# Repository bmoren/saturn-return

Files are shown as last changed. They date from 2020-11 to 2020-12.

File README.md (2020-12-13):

# saturn-return
Send transmissions, listen for communication

## ** REV2 boards are  currently untested **

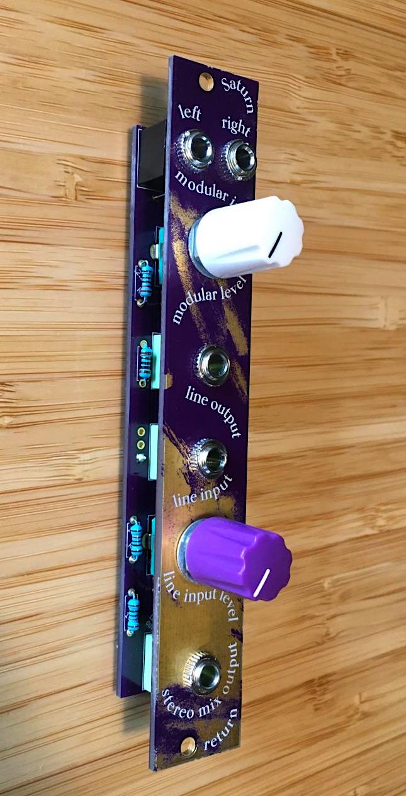
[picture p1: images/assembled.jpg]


Modular level > stereo line out &amp; stereo aux send mixer (a friend of norns)
4hp

Modular Left and Right signals are fed through a voltage divider, tuned, and sent out into space.      
Transmissions are received as stereo line signals.     
Transmissions are tuned and combined with signals (for recording and archiving).    

An module and idea based on [discussion in the norns I/O thread](https://llllllll.co/t/norns-audio-in-out-specs/30256/37?u=bmoren)

[View it on ModularGrid](https://www.modulargrid.net/e/other-unknown-saturn-return)

## I/O

Inputs:
+ L/R modular level signals
+ Line input

Outputs: 
+ Stereo line output
+ Stereo mix line output (mixed inputs)

Knobs:
+ Level control for modular input to mix
+ Level control for line input to mix

Pin headers:
support alternative I/O configurations, non-eurorack builds, and general experimentation!

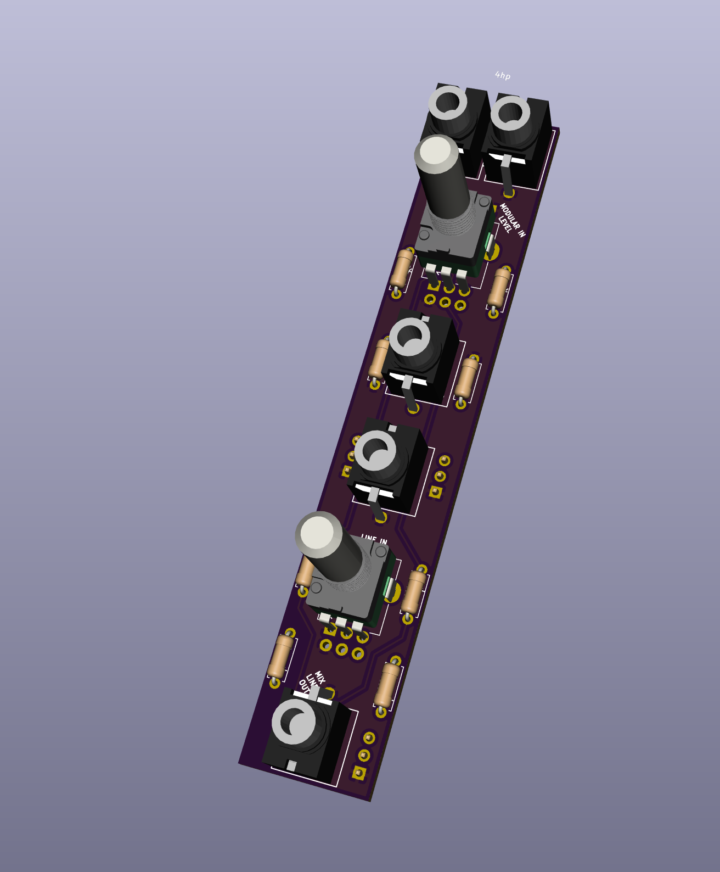
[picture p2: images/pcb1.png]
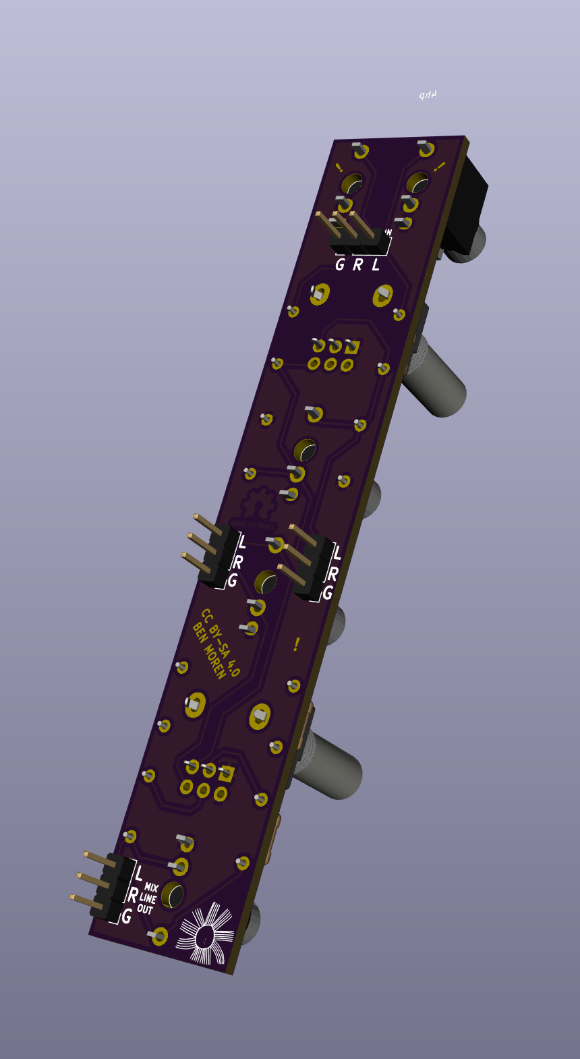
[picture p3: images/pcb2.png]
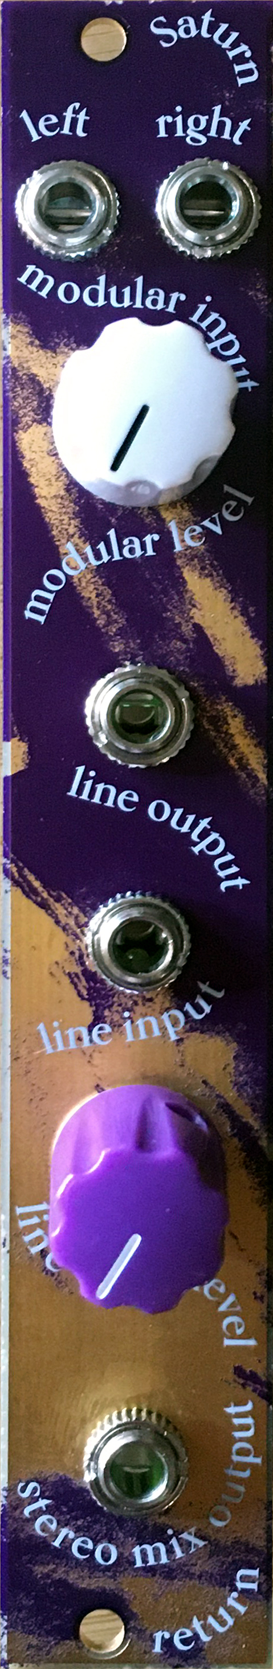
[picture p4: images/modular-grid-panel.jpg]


## Build Instructions
1. (optional advanced preperation – use your multimeter to find matched resistor values R3=R7, R4=R8, R1=R2=R5=R6 )
1. Start with the resistors, place them into the footrpints
1. Solder resistors, clip the legs
1. Place jacks and pots into the footprints. * do not solder them yet!
1. Place the panel on, screw down jacks and pots to the panel (this will align everything)
1. finally solder the jacks and panels
1. attach knobs
1. done!

## BOM
+ 2X [Thonkiconn Jacks](https://www.thonk.co.uk/shop/3-5mm-jacks/)
+ 3X [Thonkiconn Stereo Jacks](https://www.thonk.co.uk/shop/3-5mm-jacks/)
+ 2X [Alpha A10k dual gang potentiometers](https://www.thonk.co.uk/shop/alpha-9mm-pots-dshaft/)
+ 4X 10k Resistor
+ 2X 1k Resistor
+ 2X 2.2k Resistor
+ Optional: 4X 3 position 2.54mm pin header

## license 

CC BY-SA 4.0     
Build and use at your own risk! I am not responsible for any damage to self or otherwise that arises from using this project!

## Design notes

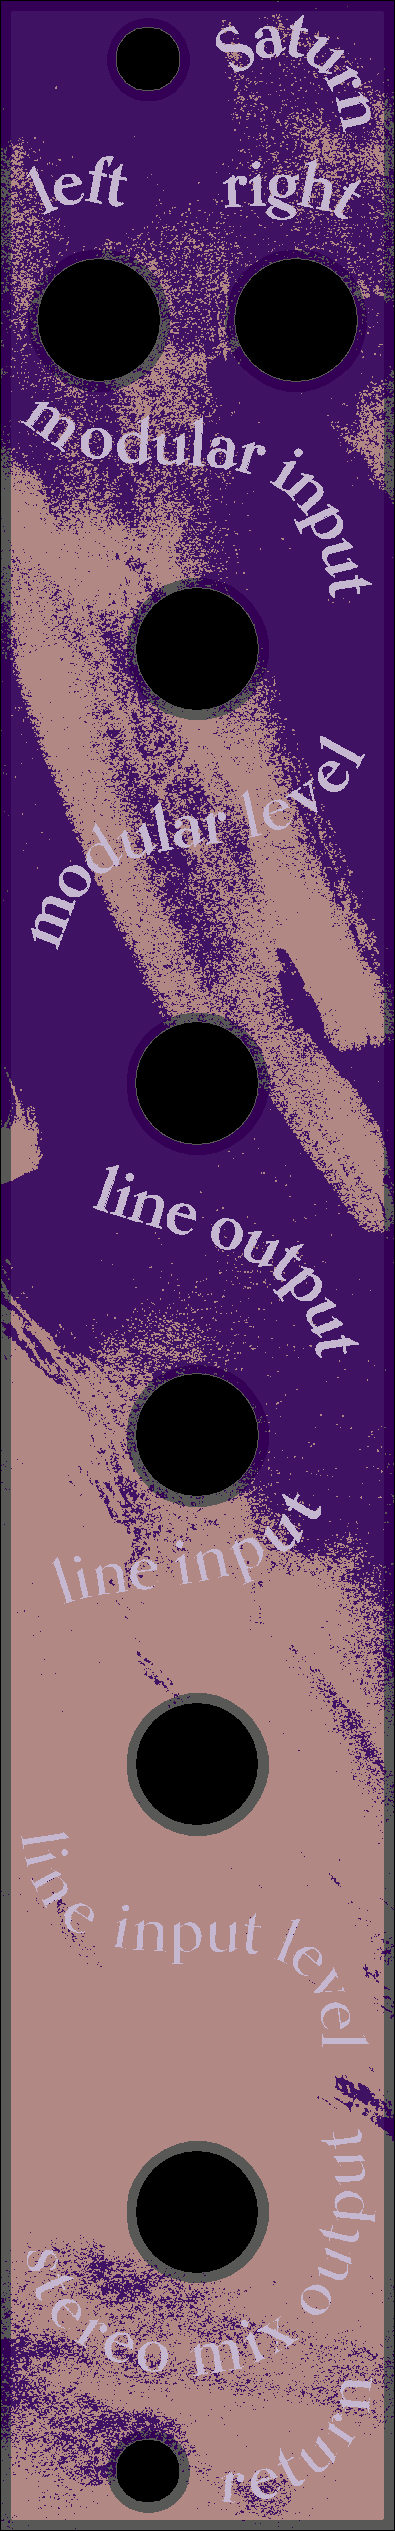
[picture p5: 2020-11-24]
images/panel.png

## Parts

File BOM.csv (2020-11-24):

Source: | /Users/bmoren/Desktop/module development/saturn return/nab.sch
Date: | Tuesday, November 24, 2020 at 02:54:47 PM
Tool: | Eeschema (5.1.6-0-10_14)
Generator: | /Applications/KiCad/kicad.app/Contents/SharedSupport/plugins/bom_csv_grouped_by_value_with_fp.py
Component Count: | 19
Ref | Qnty | Value | Cmp name | Footprint | Description | Vendor
J1, | 1 | MIX LINE OUT | AudioJack3 | modular:Thonkiconn_stereo_small_holes | Audio Jack, 3 Poles (Stereo / TRS)
J2, | 1 | LINE IN | AudioJack3 | modular:Thonkiconn_stereo_small_holes | Audio Jack, 3 Poles (Stereo / TRS)
J3, | 1 | LINE OUT | AudioJack3 | modular:Thonkiconn_stereo_small_holes | Audio Jack, 3 Poles (Stereo / TRS)
J4, | 1 | MOD IN L | thonkiconn | modular:Thonkiconn_small_holes | 2-pin audio jack receptable (mono/TS connector) with switching contact
J5, | 1 | MOD IN R | thonkiconn | modular:Thonkiconn_small_holes | 2-pin audio jack receptable (mono/TS connector) with switching contact
J6, J7, J8, J9, | 4 | Conn_01x03_Male | Conn_01x03_Male | Connector_PinHeader_2.54mm:PinHeader_1x03_P2.54mm_Vertical | Generic connector, single row, 01x03, script generated (kicad-library-utils/schlib/autogen/connector/)
R1, R2, R5, R6, | 4 | 10K | R | Resistor_THT:R_Axial_DIN0207_L6.3mm_D2.5mm_P7.62mm_Horizontal | Resistor
R3, R7, | 2 | 2.2k | R | Resistor_THT:R_Axial_DIN0207_L6.3mm_D2.5mm_P7.62mm_Horizontal | Resistor
R4, R8, | 2 | 1k | R | Resistor_THT:R_Axial_DIN0207_L6.3mm_D2.5mm_P7.62mm_Horizontal | Resistor
RV1, RV2, | 2 | A10k | R_POT_Dual_Separate | Potentiometer_THT:Potentiometer_Alpha_RD902F-40-00D_Dual_Vertical | Dual potentiometer, separate units

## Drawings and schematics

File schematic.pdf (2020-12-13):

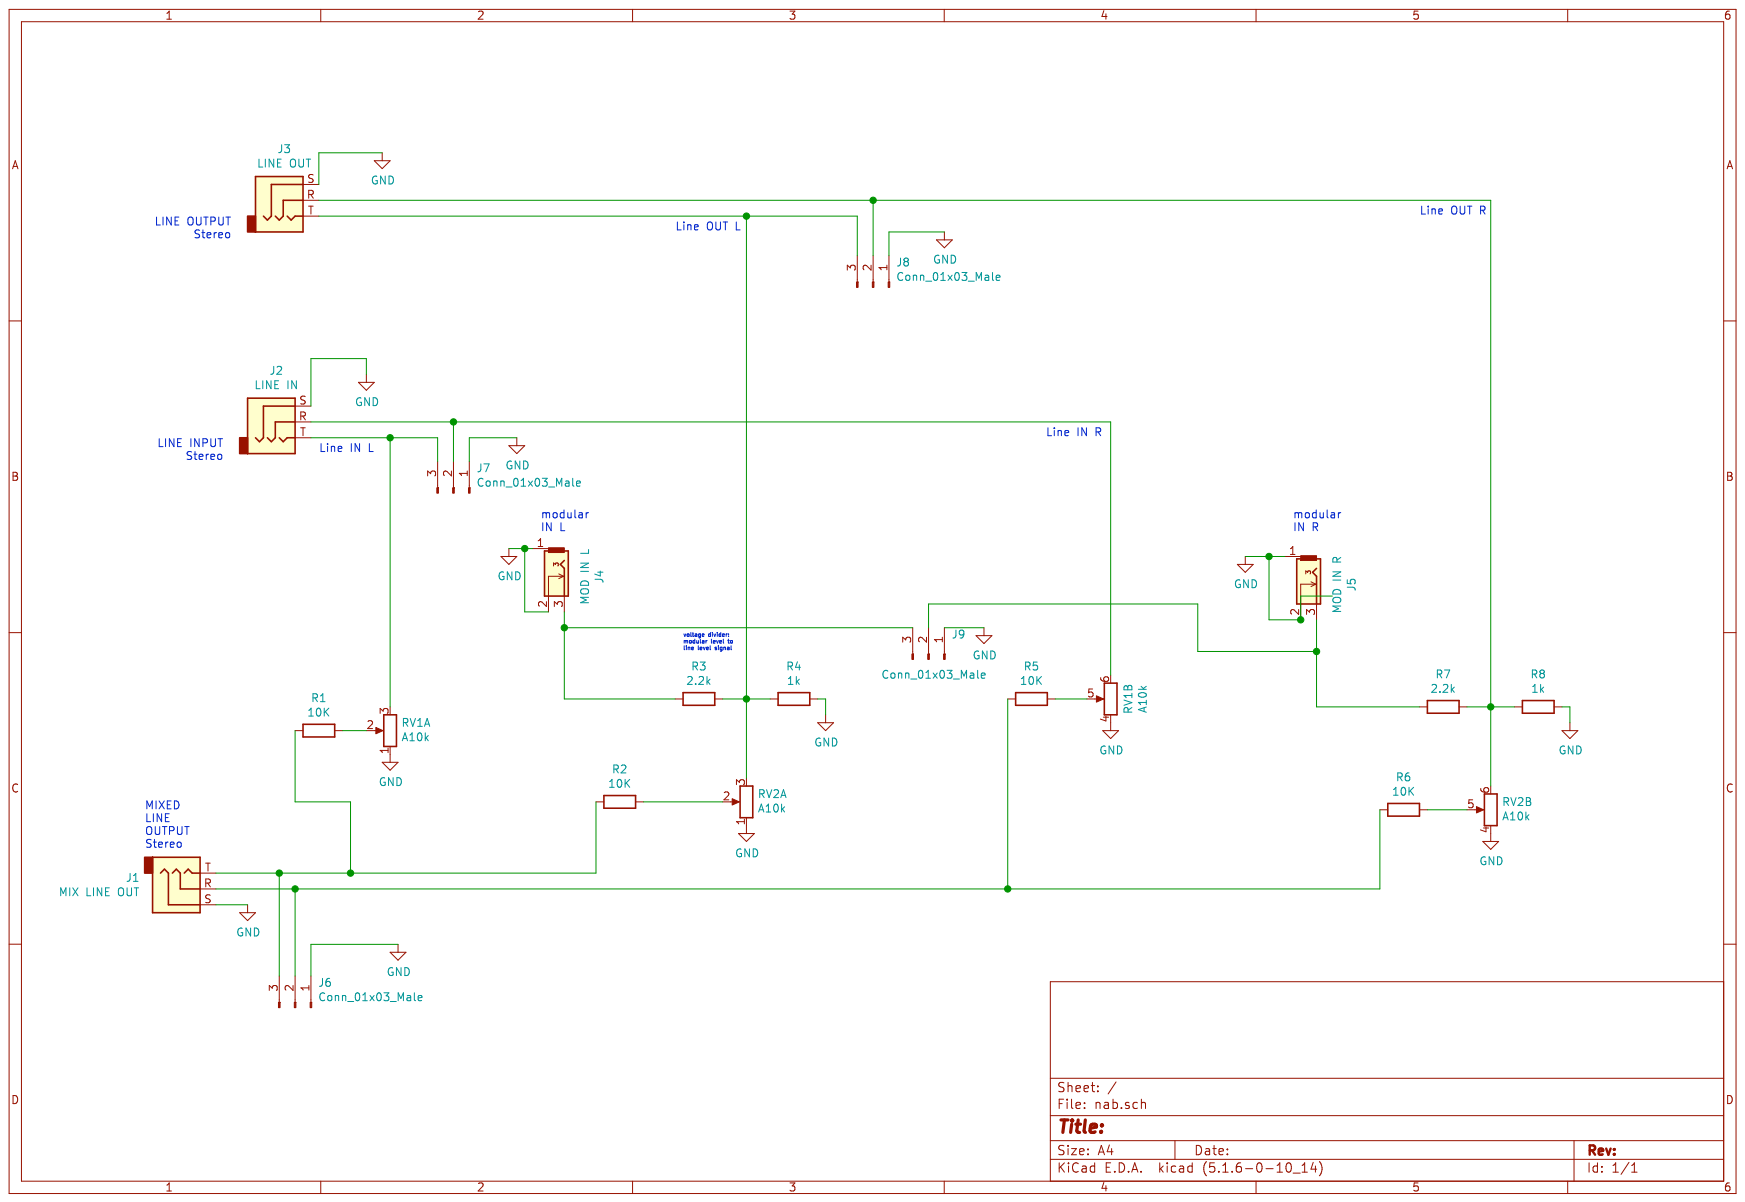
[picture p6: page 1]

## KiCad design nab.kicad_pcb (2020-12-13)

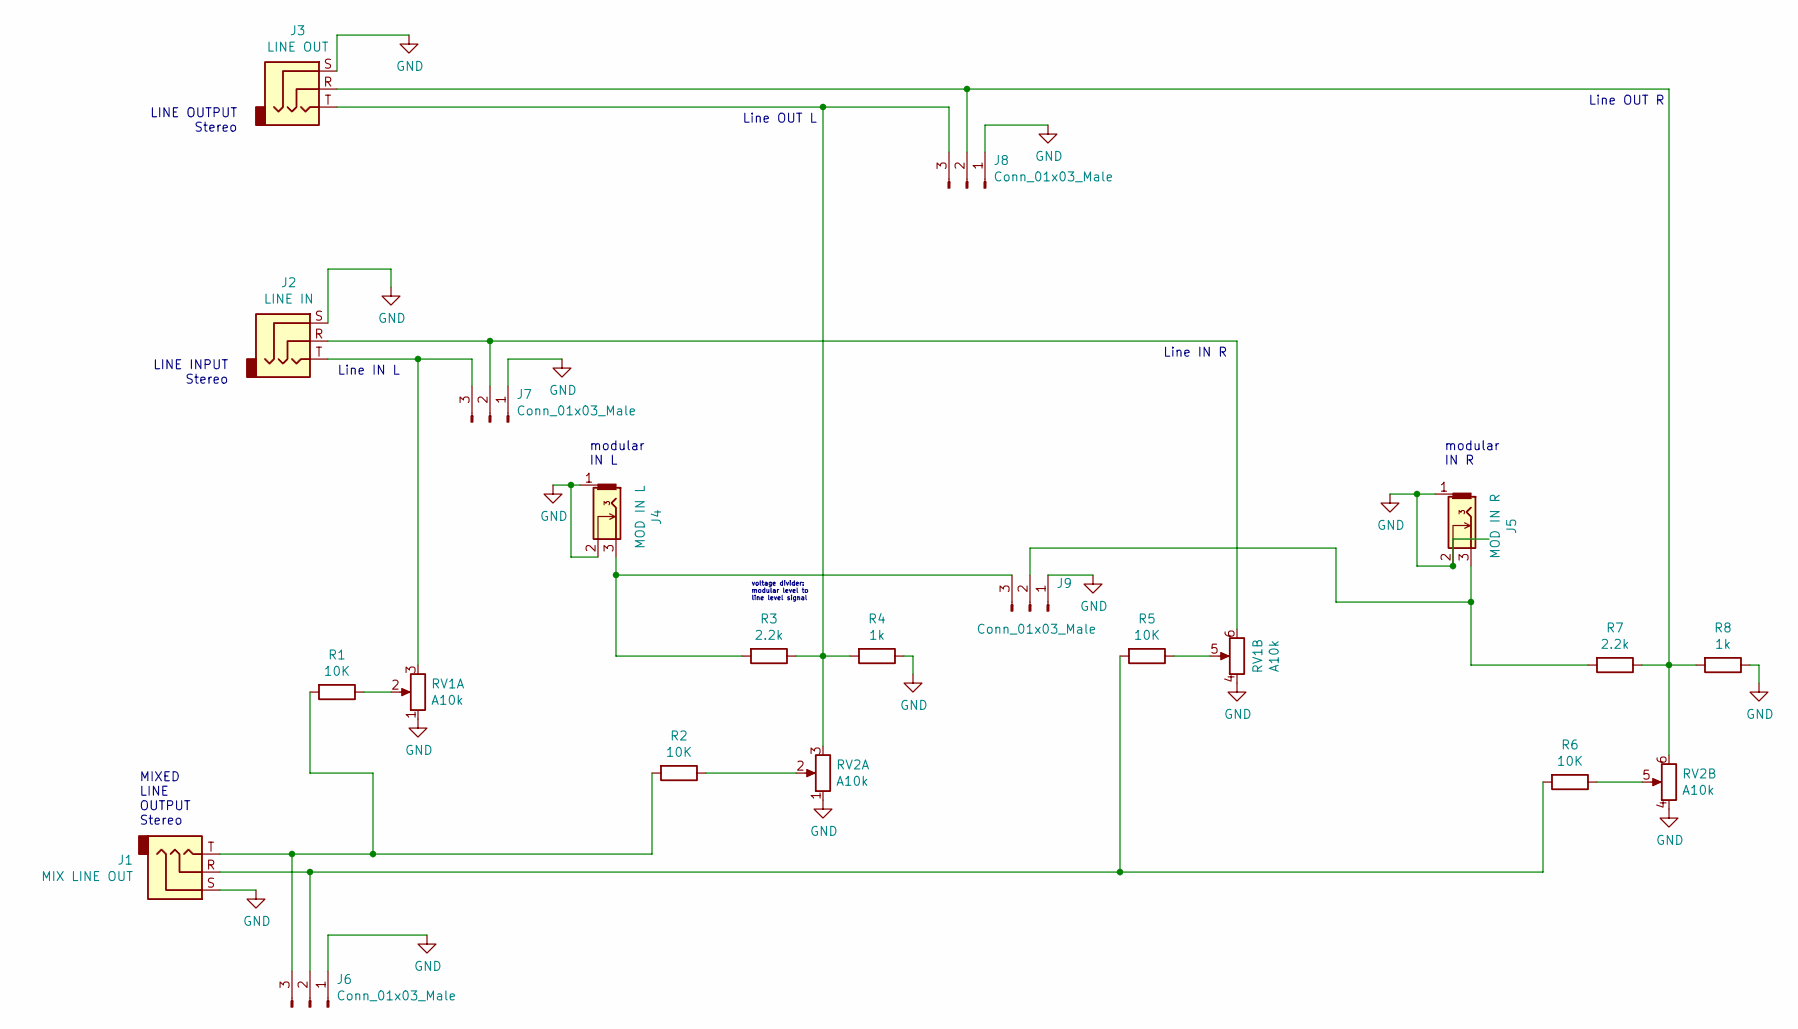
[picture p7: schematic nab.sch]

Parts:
J1: MIX LINE OUT; Thonkiconn_stereo_small_holes
J2: LINE IN; Thonkiconn_stereo_small_holes
J3: LINE OUT; Thonkiconn_stereo_small_holes
J4: MOD IN L; Thonkiconn_small_holes
J5: MOD IN R; Thonkiconn_small_holes
J6, J7, J8, J9: Conn_01x03_Male; PinHeader_1x03_P2.54mm_Vertical
R1, R2, R5, R6: 10K; R_Axial_DIN0207_L6.3mm_D2.5mm_P7.62mm_Horizontal
R3, R7: 2.2k; R_Axial_DIN0207_L6.3mm_D2.5mm_P7.62mm_Horizontal
R4, R8: 1k; R_Axial_DIN0207_L6.3mm_D2.5mm_P7.62mm_Horizontal
RV1, RV2: A10k; Potentiometer_Alpha_RD902F-40-00D_Dual_Vertical

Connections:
GND: J1.S, J2.S, J3.S, J4.1, J4.2, J5.1, J5.2, J6.1, J7.1, J8.1, J9.1, R4.1, R8.1, RV1.1, RV1.4, RV2.1, RV2.4
unnamed: J1.R, J6.2, R5.2, R6.2
unnamed: J1.T, J6.3, R1.2, R2.2
unnamed: J2.R, J7.2, RV1.6
unnamed: J2.T, J7.3, RV1.3
unnamed: J3.R, J8.2, R7.1, R8.2, RV2.6
unnamed: J3.T, J8.3, R3.1, R4.2, RV2.3
unnamed: J4.3, J9.3, R3.2
unnamed: J5.3, J9.2, R7.2
unnamed: R1.1, RV1.2
unnamed: R2.1, RV2.2
unnamed: R5.1, RV1.5
unnamed: R6.1, RV2.5

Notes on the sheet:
modular IN R
Line OUT L
Line IN R
MIXED LINE OUTPUT Stereo
LINE OUTPUT Stereo
voltage divider: modular level to line level signal
modular IN L
LINE INPUT Stereo
Line IN L
Line OUT R

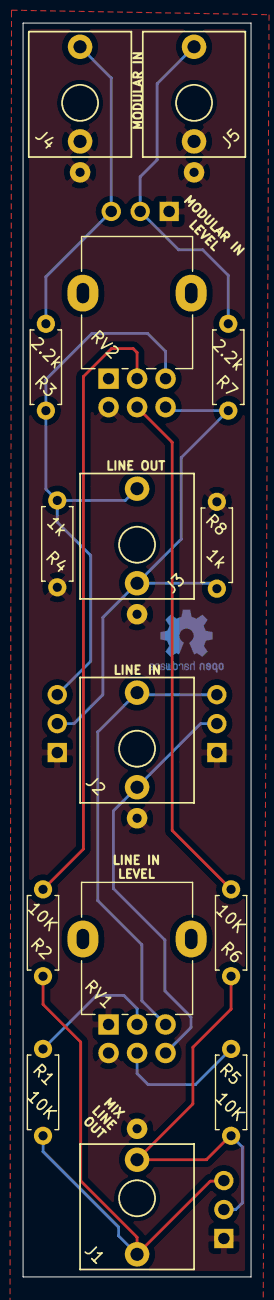
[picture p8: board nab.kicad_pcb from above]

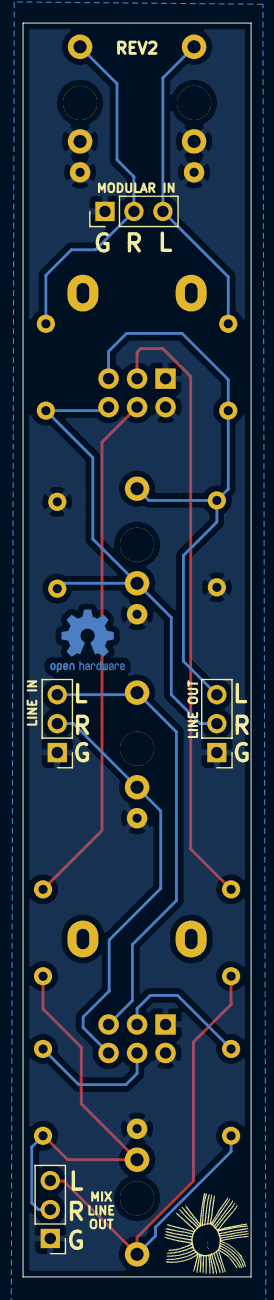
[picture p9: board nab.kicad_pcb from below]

Board: 2 copper layers, 20.0 x 110.0 mm, 19 parts (4 on the bottom side), 13 nets.

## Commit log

2020-11-25 add schematic pdf
2020-12-03 rev2 (missed a ground)
    [nab.kicad_pcb, nab.sch]
2020-12-13 add rev2 gerbs (untested)
    [auxboxPanel-B_Adhes.gbr, auxboxPanel-B_CrtYd.gbr, auxboxPanel-B_Cu.gbr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]
